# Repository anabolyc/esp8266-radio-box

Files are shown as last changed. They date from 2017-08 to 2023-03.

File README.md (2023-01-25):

# ESP8266 Radio Box

Open Source Hardware
Open Source Software

Use TEA5767/RDA5807M FM radio module in combination with ESP8266 self hosted web interface. Project includes both hardware and software components and shared via GPLv3 permissive license.

Starting from revision D (2023) it comes as DIY Kit and grows 3 physical buttons, that allowed to run Space Invader true emulator on it.



## Key features

- WifiManager with built-in captive portal for the first time Wifi configuration
- Built-in web server for mobile app like site hosting
- Websockets server for client-server communication
- Onboard RGB LED for status indication (Rev B only)
- Onboard 240x240 px TFT screen to use offline
- Built-in CH340 Serial-bridge for one-click firmware upload
- 3 physical buttons (Rev D)
- Onboard dual AAA battery socket with voltage boost converter
- Space Invaders true emulation

## Motivation

* Want to create web-interface for FM radio module which is
    * good looking
    * mobile friendly
    * self-hosted
* Later on planned also offline use, thus TFT screen
* Had much fun assemblig it, so why not make it DIY kit

## General structure

Radio module code based on good work of [Matthias Hertel](https://github.com/mathertel/Radio). 
I added support for both RDA5807 and TEA5767 modules, however RDA5807 seems to be better choice
* it has higher output power, so you can connect headphones directly
* it has hardware volume control, RDS, bass boost, mute and few more, TEA5767 has none of those
* TEA5767 seems to has better perception than RDA5807, but with a good signal doesn't make a big difference

## Space Invaders

Emulation software ported from great [repo](https://github.com/jscrane/invaders) created by [jscrane](https://github.com/jscrane/invaders)
I added keypad support (interrup based click routines, timer based long-press detection), therefore you can control it using 3 buttons. Single click gives standard "Left", "Fire", "Right" actions. Long press corresponds to "Player 1 start", "Insert Coin" and "Pause" actions.

## How to build and flash

1. Install [Platformio[(https://platformio.org/) IDE (vscode with plugin at the moment of writing)
1. Clone project with submodules `git clone --recurse-submodules https://github.com/anabolyc/esp8266-radio-box`
1. Open either [esp8266-radio-box](/firmware/esp8266-radio-box) or [esp-space-invaders](/firmware/esp-space-invaders) project in the [vscode](https://github.com/Microsoft/vscode) and build using `Build` command. Use `RadioBox-B` or `RadioBox-D` environment depending on the board revision.
1. Use `Upload Filesystem Image` task to build and upload app files used by webserver
1. Use `Upload` or `Upload and Monitor` command to flash firmware onto device.
1. RadioBox firmware uses [WiFiManager](https://github.com/tzapu/WiFiManager) for wifi configuration. First time device will not find known WiFi nework and will start its own named ESP-XXXXXX, with ChipId suffix. Connect to that network, you will be redirected to captive portal and prompted for Wifi credentials. From this moment forward device will connect to known network automatically.
1. Now enter http://device-ip or http://ESP-XXXXXX.lan adress to control Radio via app.
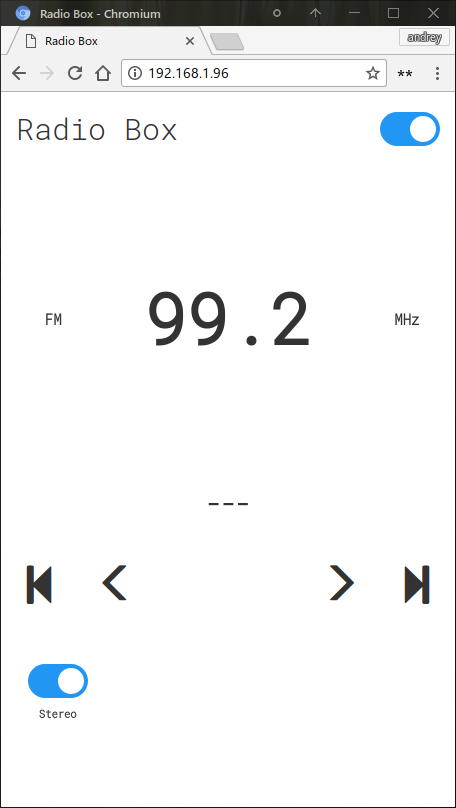
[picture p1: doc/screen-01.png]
Home screen


## How to debug web app

To debug web-interface directly in IDE (no need to upload each change to ESP)
1. run `start debug web-server` task in vscode. It assumes you have [docker](https://www.docker.com/) installed. It will start light http server on 8080 port.
2. Find this line 
```
var NODE_IP = "192.168.0.36";
```
and change to your device IP. So app is hosted on your PC now, but will talk to actual ESP via WebSockets as a backend.
3. Acces ap at http://localhost:8080,
 
## Hardware

Design files can be found in [hardware](/hardware) section.

## Kit contents 



## Assemble instructions

Please check on the [project page](https://hackaday.io/project/189326-space-invaders-radio-diy-kit)

## Look

### Revision D



### Revision B



## Where to buy

You can support my by buying kit on [Tindie](https://www.tindie.com/products/sonocotta/esp8266-radio-box/)

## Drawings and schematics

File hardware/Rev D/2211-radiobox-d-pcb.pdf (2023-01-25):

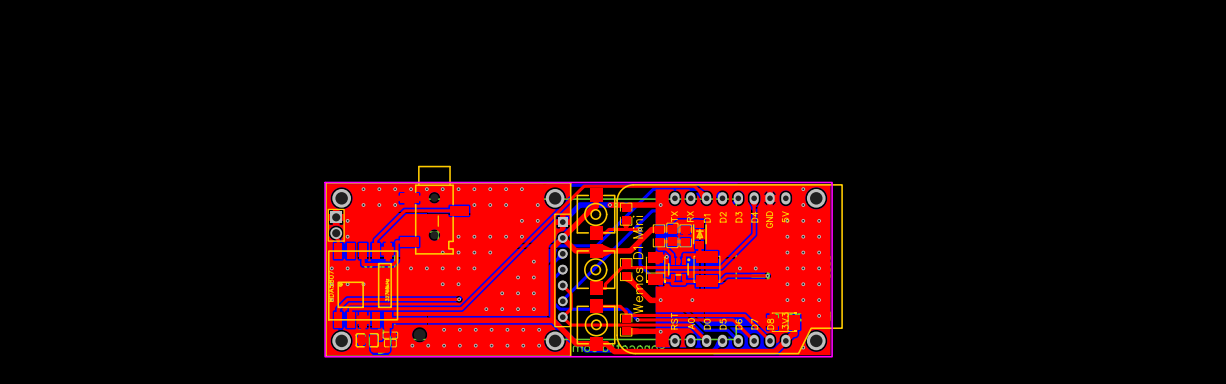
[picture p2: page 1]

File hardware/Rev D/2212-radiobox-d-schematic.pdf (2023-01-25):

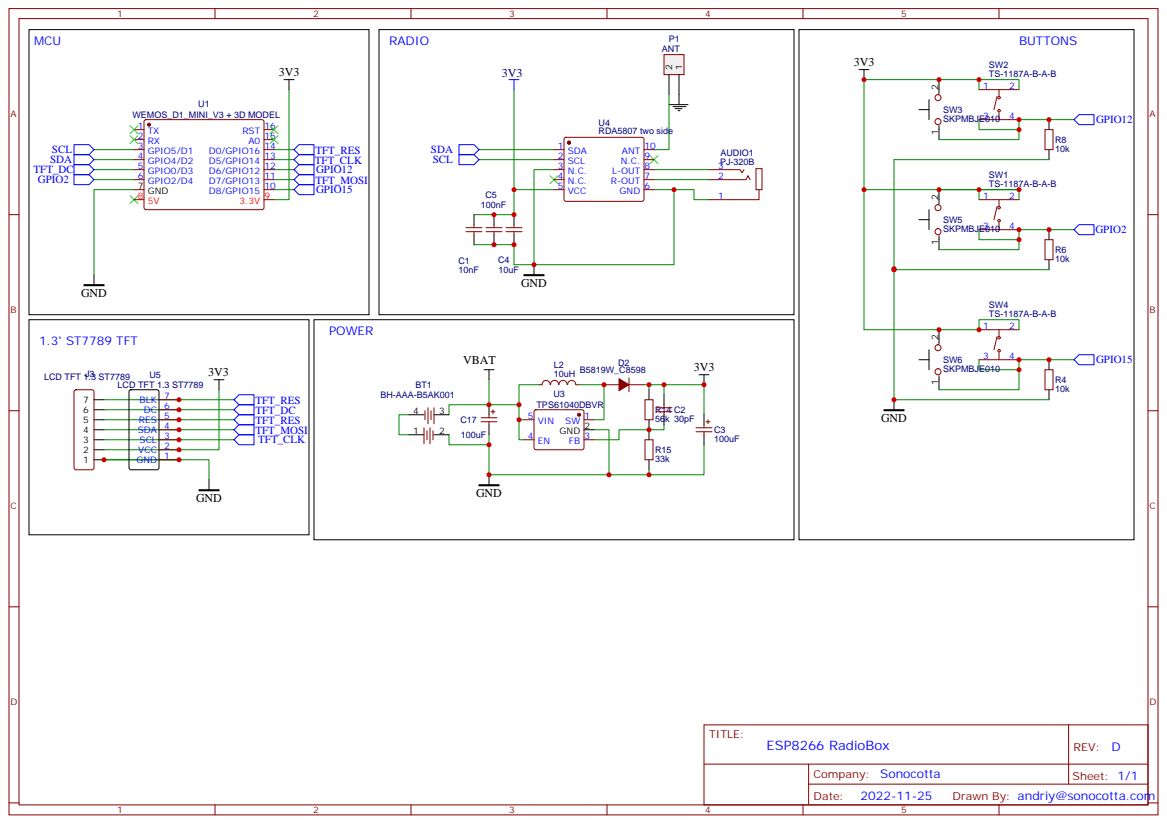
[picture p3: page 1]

Drawn By: andriy@sonocotta.com

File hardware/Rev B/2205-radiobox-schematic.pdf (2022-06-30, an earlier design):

## MCU

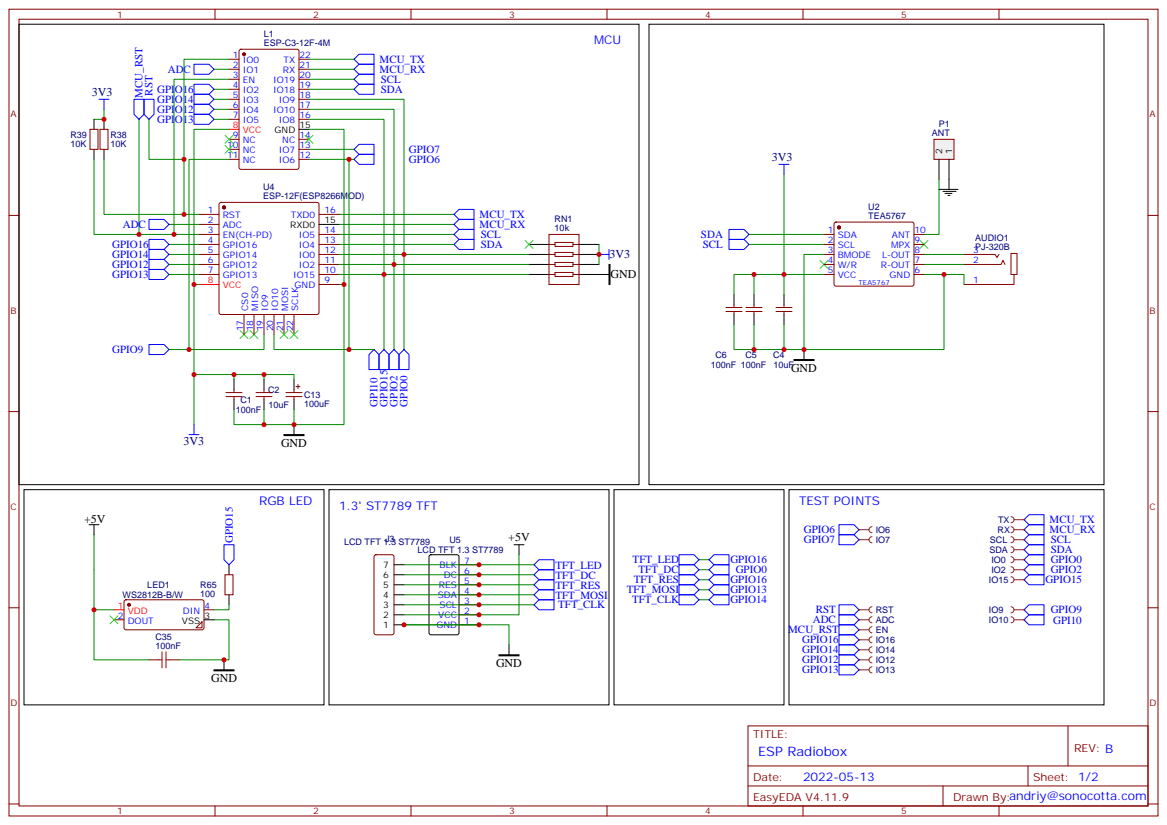
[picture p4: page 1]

POWER SELECT | 3.3V LDO

## Manual Switch

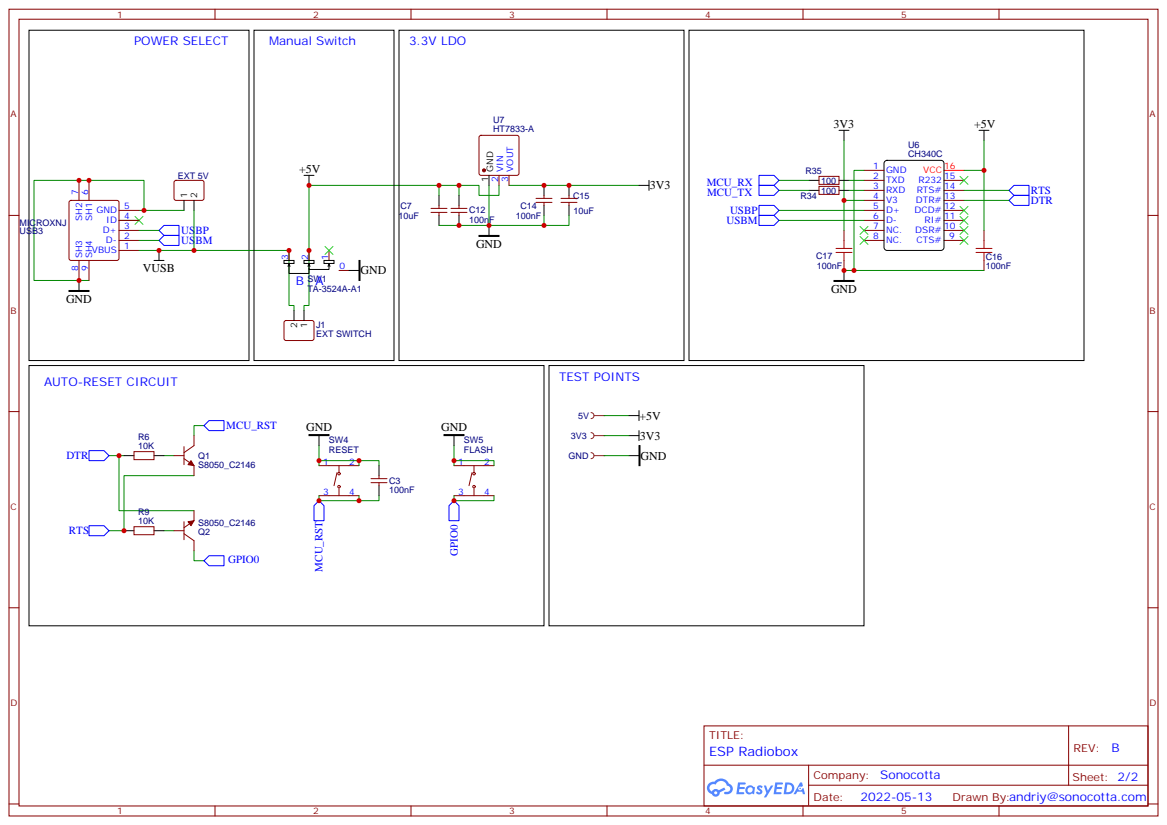
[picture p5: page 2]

Drawn By:andriy@sonocotta.com

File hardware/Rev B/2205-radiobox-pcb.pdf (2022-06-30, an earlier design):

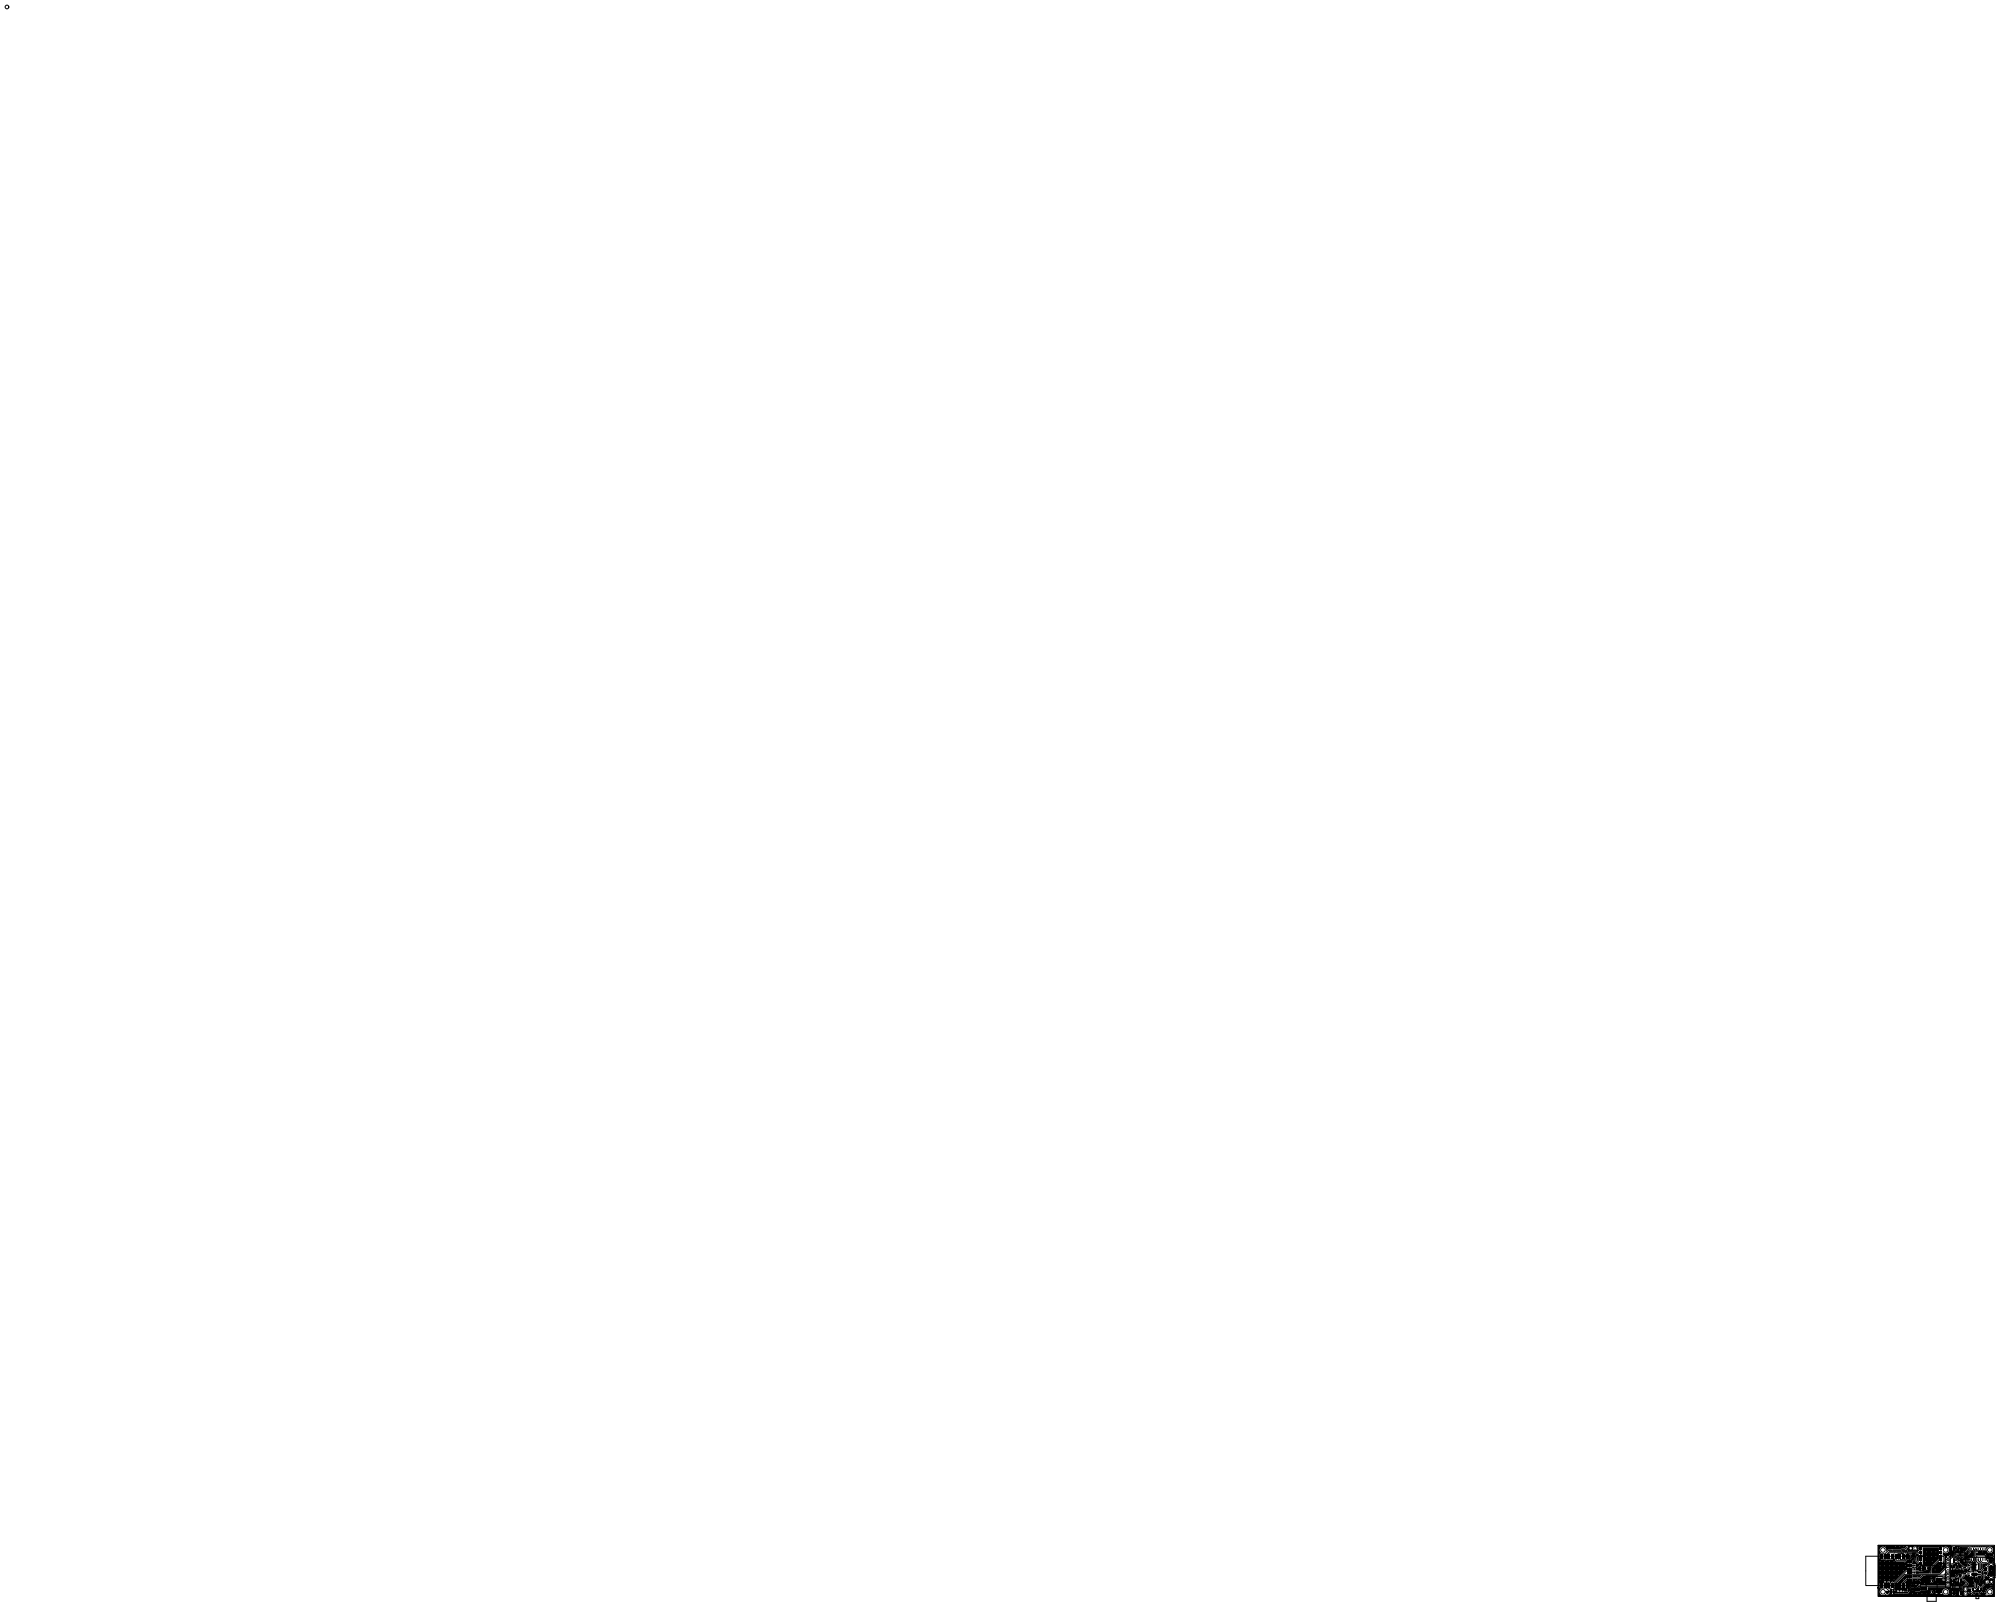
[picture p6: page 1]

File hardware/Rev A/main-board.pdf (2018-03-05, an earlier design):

## VCC

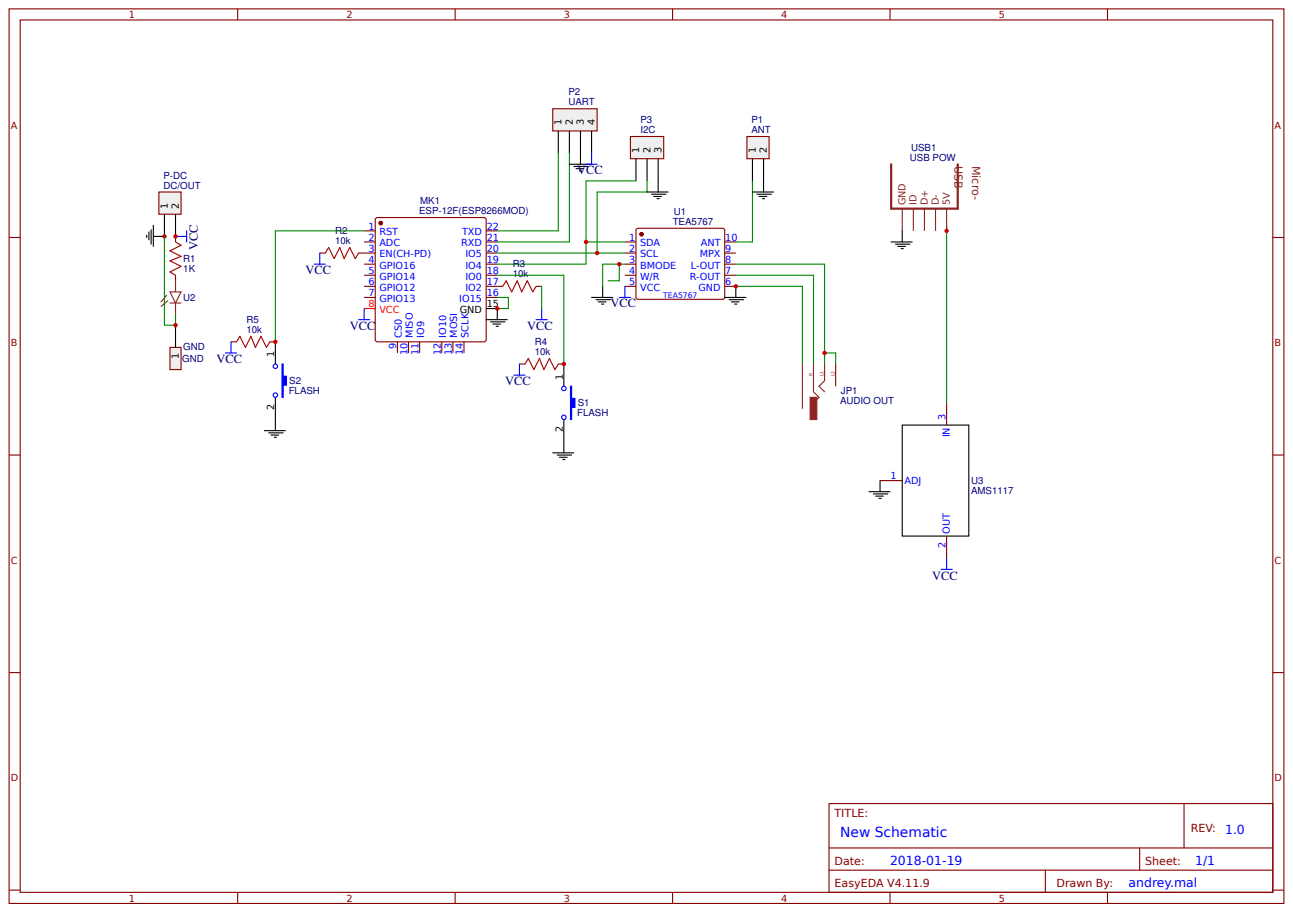
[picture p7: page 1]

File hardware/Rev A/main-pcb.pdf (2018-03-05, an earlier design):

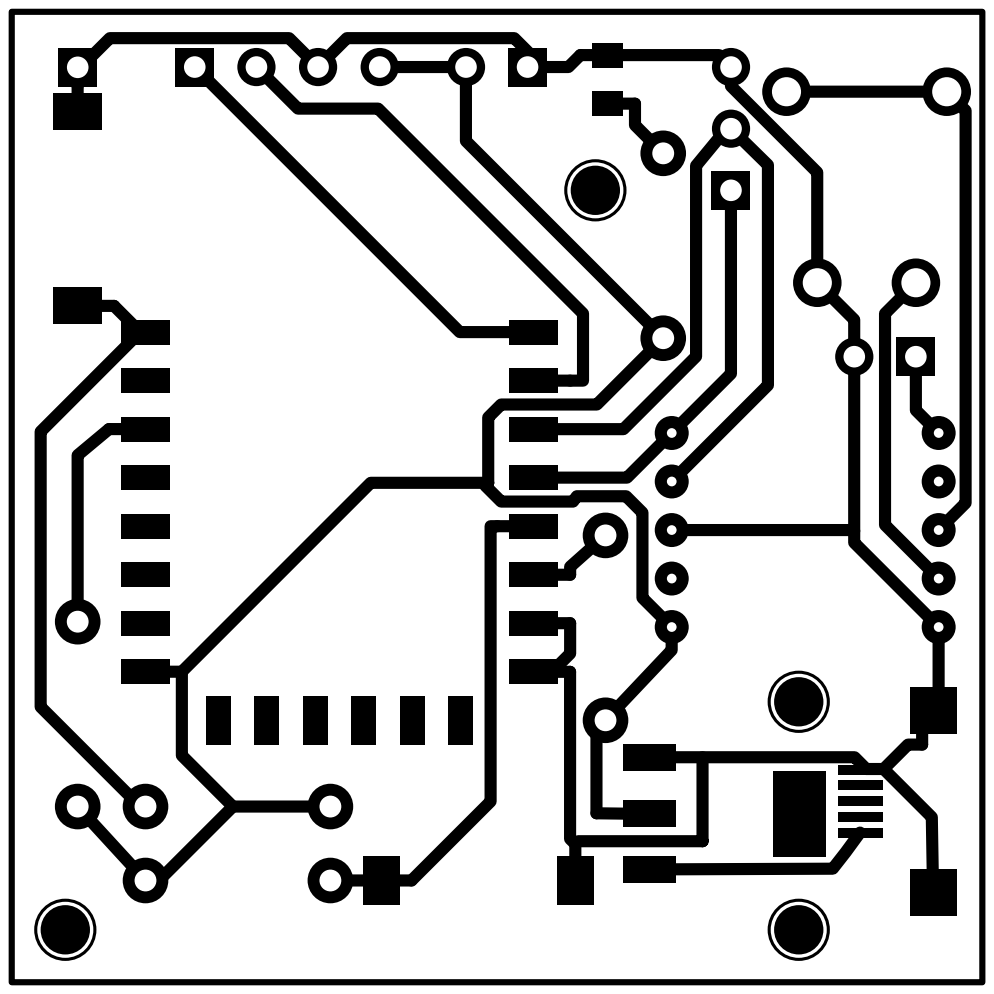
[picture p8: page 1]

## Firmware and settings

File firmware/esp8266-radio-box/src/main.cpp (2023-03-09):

#include <Arduino.h>
#include <TFT_eSPI.h>
#include <Ticker.h>

#if defined(WIFI_SSID) && defined(WIFI_PASS)
#define WIFI_STATIC
#else
#include <FS.h>
using namespace fs;
#include <WiFiManager.h>
WiFiManager wifiManager;
#endif

#if defined(PIN_LED)
#include "statusled.h"
#define ENABLE_LED
StatusLed *statusLed = new StatusLed();
#endif

#include "webserver.h"
#include "tftdisplay.h"
#include "logger.h"
#include "main.h"

static Radio *radio = new Radio();
static RadioState *state = new RadioState(RadioCaps, radio);
TFT_eSPI *tft = new TFT_eSPI();
TftDisplay *tftdisplay = new TftDisplay(tft, state);
WebServer *server = new WebServer(state);

#if defined(PIN_BTN_L) && defined(PIN_BTN_M) && defined(PIN_BTN_R)
#include <OneButton.h>
#define ENABLE_BUTTONS
OneButton *btn_l = new OneButton(PIN_BTN_L, false, false);
OneButton *btn_m = new OneButton(PIN_BTN_M, false, false);
OneButton *btn_r = new OneButton(PIN_BTN_R, false, false);
#endif

void startWifi()
{
#ifdef ESP8266
	uint32_t chipID = ESP.getChipId();
#endif
#ifdef ESP32
	uint64_t macAddress = ESP.getEfuseMac();
	uint64_t macAddressTrunc = macAddress << 40;
	uint32_t chipID = macAddressTrunc >> 40;
#endif

	String ssid = "ESP-" + String(chipID);
	logger->printf("Setting hostname to %s\n", ssid.c_str());
	WiFi.hostname(ssid);

#ifdef WIFI_STATIC
	uint8_t cnt = 0;
	WiFi.mode(WIFI_STA);
	WiFi.begin(WIFI_SSID, WIFI_PASS);
	while (WiFi.status() != WL_CONNECTED)
	{
		delay(500);
		Serial.print(".");
		cnt++;
		if (cnt > 20)
			break;
	}

	if (WiFi.status() != WL_CONNECTED)
		ESP.restart();
#else
	wifiManager.setConfigPortalBlocking(false);
	wifiManager.setConfigPortalTimeout(60);
	if (!wifiManager.autoConnect())
	{
		logger->println("Failed to connect and hit timeout");
#ifndef NO_WIFI_WAIT
		ESP.restart();
#endif
	}
#endif

	logger->printf("Connected: ");
	logger->println(WiFi.localIP());
	server->init();
#ifdef ENABLE_LED
	statusLed->setState(ApplicationState::READY);
#endif
}

void setup()
{
	logger->begin(SERIAL_BAUD);

	Wire.begin(PIN_SDA, PIN_SCL);
	radio->init();
	radio->debugEnable(DEBUG > 0);
	delay(100);

	state->init();
	logger->println("Radio services started");

	tftdisplay->init();

#ifdef ENABLE_BUTTONS
	pinMode(PIN_BTN_L, INPUT);
	pinMode(PIN_BTN_M, INPUT);
	pinMode(PIN_BTN_R, INPUT);

	btn_l->attachClick([]()
					   {
        Serial.println("Button L clicked");
		if (state->volume > 1)
        	radio->setVolume(state->volume - 1);
		else 
			radio->setMute(true); });

	btn_l->attachLongPressStart([]()
								{
        Serial.println("Button L long press");
        radio->seekDown(); });

	btn_m->attachClick([]()
					   {
        Serial.println("Button M clicked");
        radio->setMono(!radio->getMono()); });

	btn_r->attachClick([]()
					   {
        Serial.println("Button R clicked");
		if (radio->getMute())
			 radio->setMute(false);
        radio->setVolume(state->volume + 1); });

	btn_r->attachLongPressStart([]()
								{
        Serial.println("Button R long press");
        radio->seekUp(); });
#endif

	startWifi();
}

void loop()
{
	server->loop();

#ifdef ENABLE_BUTTONS
	btn_l->tick();
	btn_m->tick();
	btn_r->tick();
#endif
}

void rdsCallBack(uint16_t block1, uint16_t block2, uint16_t block3, uint16_t block4)
{
	logger->println("RDS: ");
	logger->println(block1);
	logger->println(block2);
	logger->println(block3);
	logger->println(block4);
	logger->println("-----");
}

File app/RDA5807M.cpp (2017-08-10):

/// \file RDA5807M.cpp
/// \brief Implementation for the radio library to control the RDA5807M radio chip.
///
/// \author Matthias Hertel, http://www.mathertel.de
/// \copyright Copyright (c) 2014-2015 by Matthias Hertel.\n
/// This work is licensed under a BSD style license.\n
/// See http://www.mathertel.de/License.aspx
///
/// This library enables the use of the radio chip RDA5807M from http://www.rdamicro.com/.
///
/// More documentation and source code is available at http://www.mathertel.de/Arduino
///
/// History:
/// --------
/// * 05.08.2014 created.
#include <RDA5807M.h>

// initialize the extra variables in RDA5807M
RDA5807M::RDA5807M() {
  // t.b.d. ???
}

// initialize all internals.
bool RDA5807M::init() {
  bool result = false; // no chip found yet.
  DEBUG_FUNC0("init");

  Wire.begin();
  Wire.beginTransmission(I2C_INDX);
  result = Wire.endTransmission();
  if (result == 0) {
    DEBUG_STR("radio found.");
    result = true;

    // initialize all registers
    registers[RADIO_REG_CHIPID] = 0x5804;  // 00 id
    registers[1] = 0x0000;  // 01 not used
    registers[RADIO_REG_CTRL] = (RADIO_REG_CTRL_RESET | RADIO_REG_CTRL_ENABLE);
    setBand(RADIO_BAND_FM);
    registers[RADIO_REG_R4] = RADIO_REG_R4_EM50;//  0x1800;  // 04 DE ? SOFTMUTE
    registers[RADIO_REG_VOL] = 0x9081; // 0x81D1;  // 0x82D1 / INT_MODE, SEEKTH=0110,????, Volume=1
    registers[6] = 0x0000;
    registers[7] = 0x0000;
    registers[8] = 0x0000;
    registers[9] = 0x0000;

    // reset the chip
    _saveRegisters();

    registers[RADIO_REG_CTRL] = RADIO_REG_CTRL_ENABLE;
    _saveRegister(RADIO_REG_CTRL);
  }  // if
  return(result);
} // init()


// switch the power off
void RDA5807M::term()
{
  DEBUG_FUNC0("term");
  setVolume(0);
  registers[RADIO_REG_CTRL] = 0x0000;   // all bits off
  _saveRegisters();
} // term


// ----- Volume control -----

void RDA5807M::setVolume(uint8_t newVolume)
{
  RADIO::setVolume(newVolume);
  newVolume &= RADIO_REG_VOL_VOL;
  registers[RADIO_REG_VOL] &= (~RADIO_REG_VOL_VOL);
  registers[RADIO_REG_VOL] |= newVolume;
  _saveRegister(RADIO_REG_VOL);
} // setVolume()


void RDA5807M::setBassBoost(bool switchOn)
{
  RADIO::setBassBoost(switchOn);
  uint16_t regCtrl = registers[RADIO_REG_CTRL];
  if (switchOn)
  regCtrl |= RADIO_REG_CTRL_BASS;
  else
  regCtrl &= (~RADIO_REG_CTRL_BASS);
  registers[RADIO_REG_CTRL] = regCtrl;
  _saveRegister(RADIO_REG_CTRL);
} // setBassBoost()


// Mono / Stereo
void RDA5807M::setMono(bool switchOn)
{
  RADIO::setMono(switchOn);

  registers[RADIO_REG_CTRL] &= (~RADIO_REG_CTRL_SEEK);
  if (switchOn) {
    registers[RADIO_REG_CTRL] |= RADIO_REG_CTRL_MONO;
  }
  else {
    registers[RADIO_REG_CTRL] &= ~RADIO_REG_CTRL_MONO;
  }
  _saveRegister(RADIO_REG_CTRL);
} // setMono


// Switch mute mode.
void RDA5807M::setMute(bool switchOn)
{
  RADIO::setMute(switchOn);

  if (switchOn) {
    // now don't unmute
    registers[RADIO_REG_CTRL] &= (~RADIO_REG_CTRL_UNMUTE);
  }
  else {
    // now unmute
    registers[RADIO_REG_CTRL] |= RADIO_REG_CTRL_UNMUTE;
  } // if
  _saveRegister(RADIO_REG_CTRL);
} // setMute()


// Switch softmute mode.
void RDA5807M::setSoftMute(bool switchOn)
{
  RADIO::setSoftMute(switchOn);

  if (switchOn) {
    registers[RADIO_REG_R4] |= (RADIO_REG_R4_SOFTMUTE);
  }
  else {
    registers[RADIO_REG_R4] &= (~RADIO_REG_R4_SOFTMUTE);
  } // if
  _saveRegister(RADIO_REG_R4);
} // setSoftMute()


// ----- Band and frequency control methods -----

// tune to new band.
void RDA5807M::setBand(RADIO_BAND newBand) {
  uint16_t r;
  RADIO::setBand(newBand);

  if (newBand == RADIO_BAND_FM)
    r = RADIO_REG_CHAN_BAND_FM;
  else if (newBand == RADIO_BAND_FMWORLD)
    r = RADIO_REG_CHAN_BAND_FMWORLD;
  registers[RADIO_REG_CHAN] = (r | RADIO_REG_CHAN_SPACE_100);
} // setBand()


// retrieve the real frequency from the chip after automatic tuning.
RADIO_FREQ RDA5807M::getFrequency() {
  // check register A
  
  while (true) {
    Wire.requestFrom(I2C_SEQ, 2);
    uint16_t readValue = _read16();
    if (readValue != 0xffff) {
      registers[RADIO_REG_RA] = readValue;
      Wire.endTransmission();
      break;
    }
  }

  uint16_t ch = registers[RADIO_REG_RA] & RADIO_REG_RA_NR;
/*
  Serial.println("----FREQ----");
  Serial.print(" reg = ");
  Serial.print(registers[RADIO_REG_RA]);
  Serial.print(" 0xffff = ");
  Serial.print(0xffff);
  Serial.print(" ch = ");
  Serial.print(ch);
  Serial.print(" _freqLow = ");
  Serial.println(_freqLow);
  Serial.println("------------");
*/
  _freq = _freqLow + (ch * 10);  // assume 100 kHz spacing
  return (_freq);
}  // getFrequency


void RDA5807M::setFrequency(RADIO_FREQ newF) {
  DEBUG_FUNC1("setFrequency", newF);
  uint16_t newChannel;
  uint16_t regChannel = registers[RADIO_REG_CHAN] & (RADIO_REG_CHAN_SPACE | RADIO_REG_CHAN_BAND);

  if (newF < _freqLow) newF = _freqLow;
  if (newF > _freqHigh) newF = _freqHigh;
  newChannel = (newF - _freqLow) / 10;

  regChannel += RADIO_REG_CHAN_TUNE; // enable tuning
  regChannel |= newChannel << 6;
  
  // enable output and unmute
  registers[RADIO_REG_CTRL] |= RADIO_REG_CTRL_OUTPUT | RADIO_REG_CTRL_UNMUTE | RADIO_REG_CTRL_RDS | RADIO_REG_CTRL_ENABLE; //  | RADIO_REG_CTRL_NEW
  _saveRegister(RADIO_REG_CTRL);

  registers[RADIO_REG_CHAN] = regChannel;
  _saveRegister(RADIO_REG_CHAN);

  // adjust Volume
  _saveRegister(RADIO_REG_VOL);
} // setFrequency()


// start seek mode upwards
void RDA5807M::seekUp(bool toNextSender) {
  // start seek mode
  registers[RADIO_REG_CTRL] |= RADIO_REG_CTRL_SEEKUP;
  registers[RADIO_REG_CTRL] |= RADIO_REG_CTRL_SEEK;
  _saveRegister(RADIO_REG_CTRL);

  if (! toNextSender) {
    // stop scanning right now
    registers[RADIO_REG_CTRL] &= (~RADIO_REG_CTRL_SEEK);
    _saveRegister(RADIO_REG_CTRL);
  } // if
} // seekUp()


// start seek mode downwards
void RDA5807M::seekDown(bool toNextSender) {
  registers[RADIO_REG_CTRL] &= (~RADIO_REG_CTRL_SEEKUP);
  registers[RADIO_REG_CTRL] |= RADIO_REG_CTRL_SEEK;
  _saveRegister(RADIO_REG_CTRL);

  if (! toNextSender) {
    // stop scanning right now
    registers[RADIO_REG_CTRL] &= (~RADIO_REG_CTRL_SEEK);
    _saveRegister(RADIO_REG_CTRL);
  } // if
} // seekDown()


// Load all status registers from to the chip
// registers 0A through 0F
// using the sequential read access mode.
void RDA5807M::_readRegisters()
{
  Wire.requestFrom (I2C_SEQ, (6 * 2) );
  for (int i = 0; i < 6; i++) {
    registers[0xA+i] = _read16();
  }
  Wire.endTransmission();
}


// Save writable registers back to the chip
// The registers 02 through 06, containing the configuration
// using the sequential write access mode.
void RDA5807M::_saveRegisters()
{
  DEBUG_FUNC0("-saveRegisters");
  Wire.beginTransmission(I2C_SEQ);
  for (int i = 2; i <= 6; i++)
  _write16(registers[i]);
  Wire.endTransmission();
} // _saveRegisters
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

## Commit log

2017-07-27 Added backend wireframe
2017-07-30 Added websockets wireframe to frontend, added offline state. Added basic SSD1306 support
2017-07-31 Fixed Wire issues
2017-07-31 Prepared volume change wireframe
2017-08-01 frontend binding, backend fixup and cleaning
    [RadioScreen.h]
2017-08-01 Fixed radio initialization - frontend sync
    [RadioScreen.h, TEA5767.cpp]
2017-08-02 switched to rda5807 modulte. minor fixups. added timer for updaing ws clients
    [RDA5807M.cpp]
2017-08-10 Fixups, cleanup, screen removal, front-end improvements
    [RDA5807M.cpp, RadioScreen.h, TEA5767.cpp]
2017-08-10 Fixed volume reset by power button
    [RDA5807M.cpp]
2022-06-30 Restructured project to Platformio, no longer depends on Sming framework. Added TFT screen support. Added RGB LED support. Added WifiManager insted of hardcoded wifi credentials.
    [RDA5807M.cpp, TEA5767.cpp, main.cpp]
2022-06-30 Updated docs
    [Drill_NPTH_Through.DRL, Drill_PTH_Through.DRL, Gerber_BoardOutlineLayer.GKO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]
2026-10-21 Add ESPHome Sendspin remote firmware (#3)
    ESPHome firmware that turns the Radio Box into a Home Assistant remote:
    a now-playing screen and remote control for Music Assistant speakers
    over Sendspin, plus lists and a lights screen driven through Home
    Assistant.
    - Now playing: cover art (cross-fade), title/artist, progress, top bar
    with playback state, clock and volume; splash screen while connecting
    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
